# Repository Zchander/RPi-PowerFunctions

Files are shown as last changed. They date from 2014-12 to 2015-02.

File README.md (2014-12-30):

RPi-PowerFunctions
==================

A project to send commands over IR to a LEGO PowerFunctions receiver using an Raspberry Pi, I2C and an ATtiny2313

The Eagle project files have been added (including the PCB designs), as are the XMLRPC server files.

I'll try to update/create READMEs for the sub folders in the near future. Unfortunately my documenting skills are a bit 'subzero'

For this project I would like to thank a few people, who I will list down here. Please note that the order is random!
- Jurriaan Pruis (https://github.com/jurriaan/) for his project which gave me the idea(s)
- Dick de Wit (www.dansendelichtjes.nl) who helped me refresh some of my electronics skills
- A few from www.avrfreaks.net, some I will mention explicit:
- - kk6gm for inspiring me to NOT use _delay_ms/_delay_us in my code, but to use interrupts
- - kartman for his tutorial on multitasking on the AVR environment
- - david.prentice for directing me into a bug I introduced myself during code cleanup
- - clawson for his inspiring and helpful comments overall

(If I forgot someone, please let me know so I can include you on the list)

Xander

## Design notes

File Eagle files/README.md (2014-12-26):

The Eagle file(s) are made with version 7.2.0 and only contain the schematics. The PCB designs still have to be made.

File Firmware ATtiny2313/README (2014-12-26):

This version of the firmware is for the test environment without any external clock source. if you want to use an external clock, change the appropriate fuse settings and the define in the source(s). (This should be easy to find)

Xander

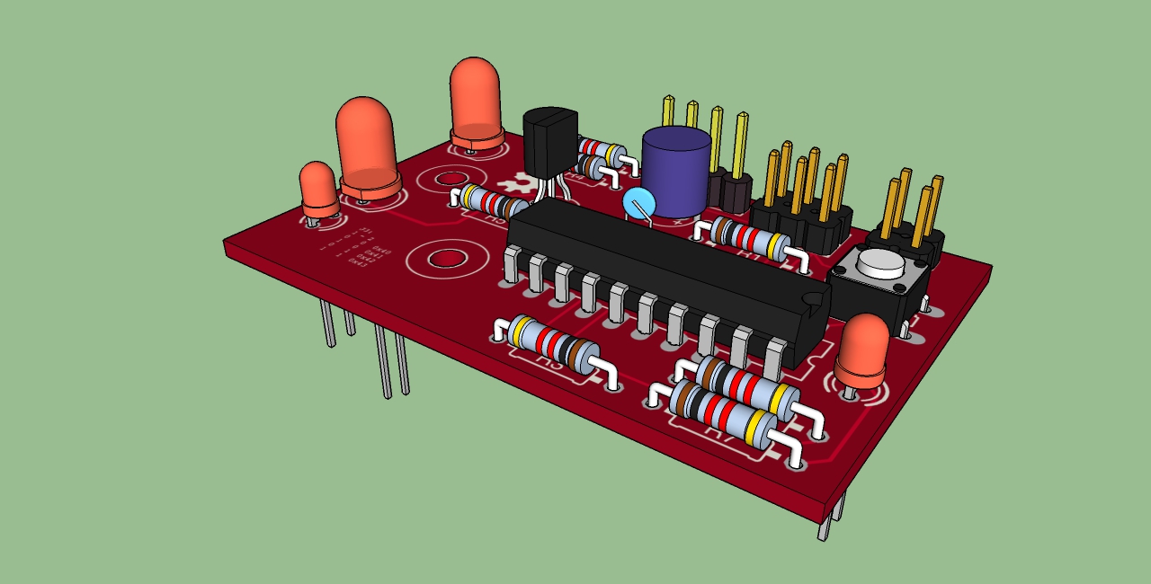
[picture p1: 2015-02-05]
Eagle files/RPi Lego PowerFunctions I2C/eagleUp/I2C Board Impression.jpg

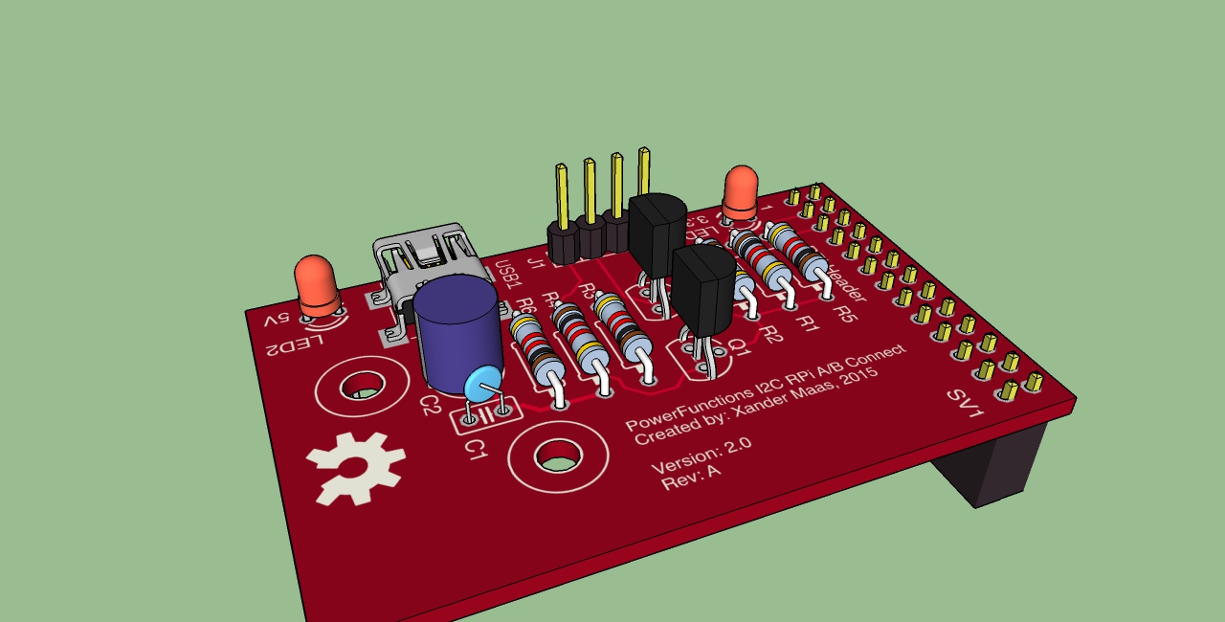
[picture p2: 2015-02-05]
Eagle files/RPi Lego PowerFunctions I2C/eagleUp/Impression I2C Connect Board.jpg

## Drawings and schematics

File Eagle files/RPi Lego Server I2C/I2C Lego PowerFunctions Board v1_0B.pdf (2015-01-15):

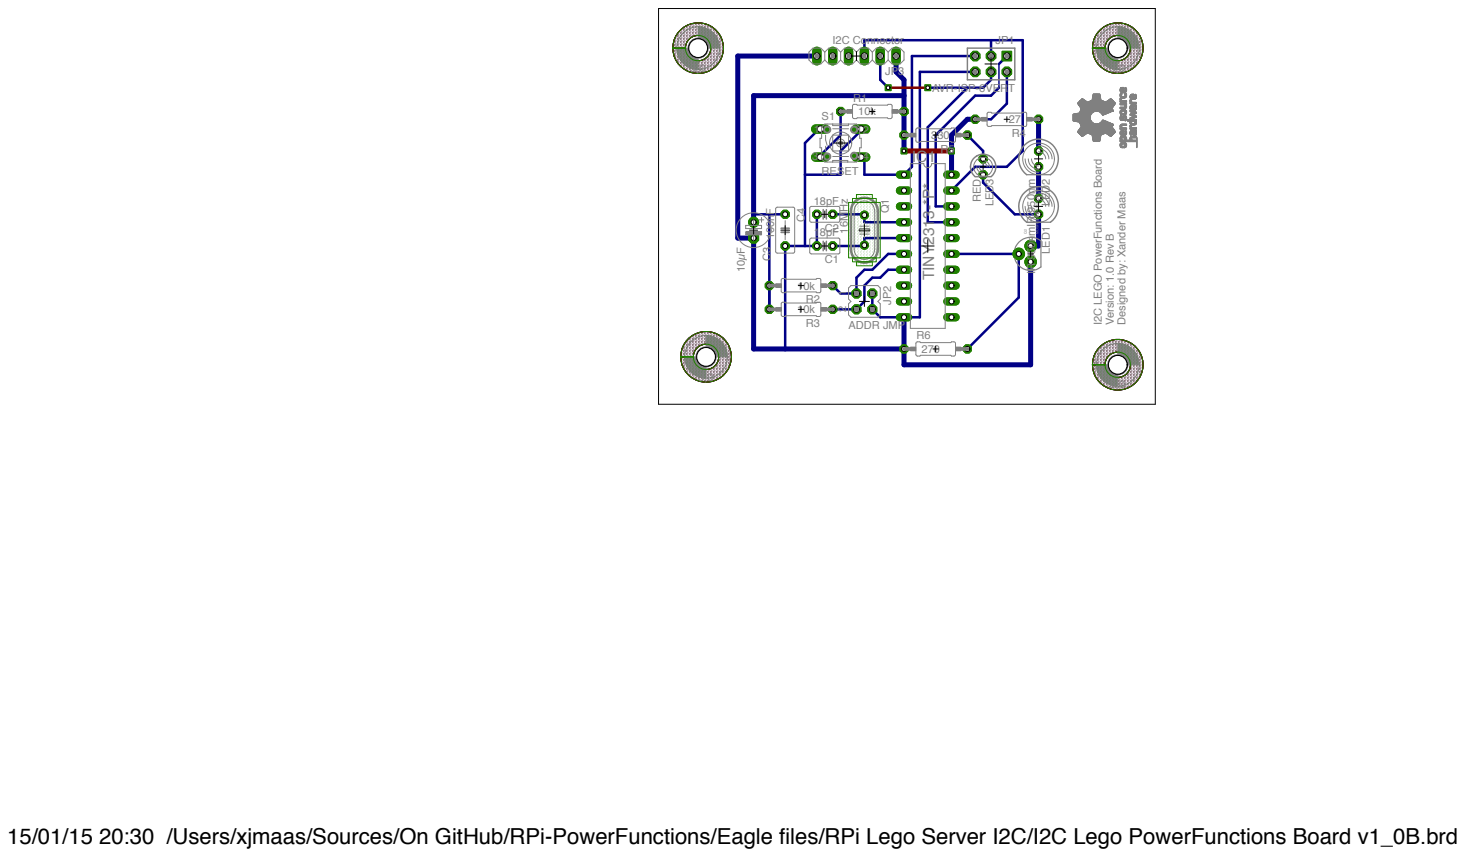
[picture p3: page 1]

15/01/15 20:30 /Users/xjmaas/Sources/On GitHub/RPi-PowerFunctions/Eagle files/RPi Lego Server I2C/I2C Lego PowerFunctions Board v1_0B.brd I2C LEGO PowerFunctions Board Version: 1.0 Rev B Designed by: Xander Maas

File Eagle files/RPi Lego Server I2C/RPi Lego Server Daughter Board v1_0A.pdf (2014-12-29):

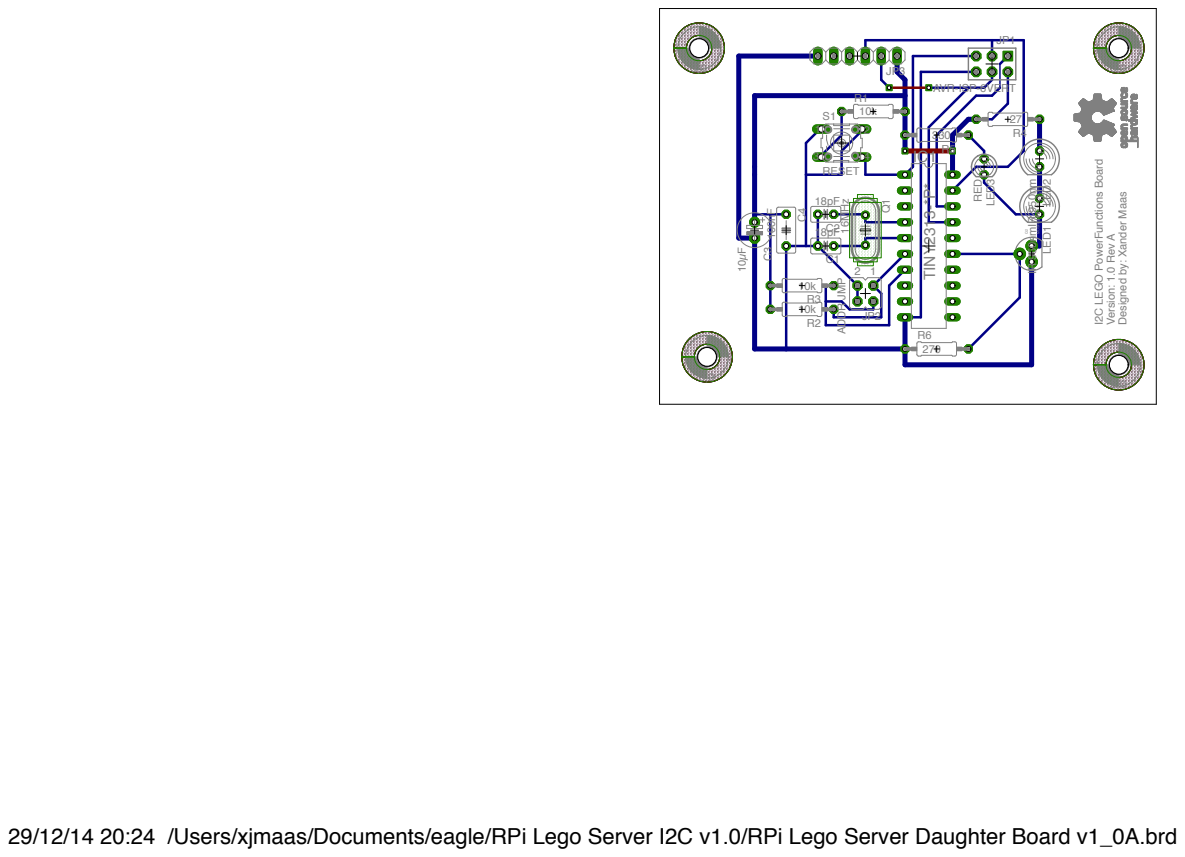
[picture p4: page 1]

29/12/14 20:24 /Users/xjmaas/Documents/eagle/RPi Lego Server I2C v1.0/RPi Lego Server Daughter Board v1_0A.brd I2C LEGO PowerFunctions Board Version: 1.0 Rev A Designed by: Xander Maas

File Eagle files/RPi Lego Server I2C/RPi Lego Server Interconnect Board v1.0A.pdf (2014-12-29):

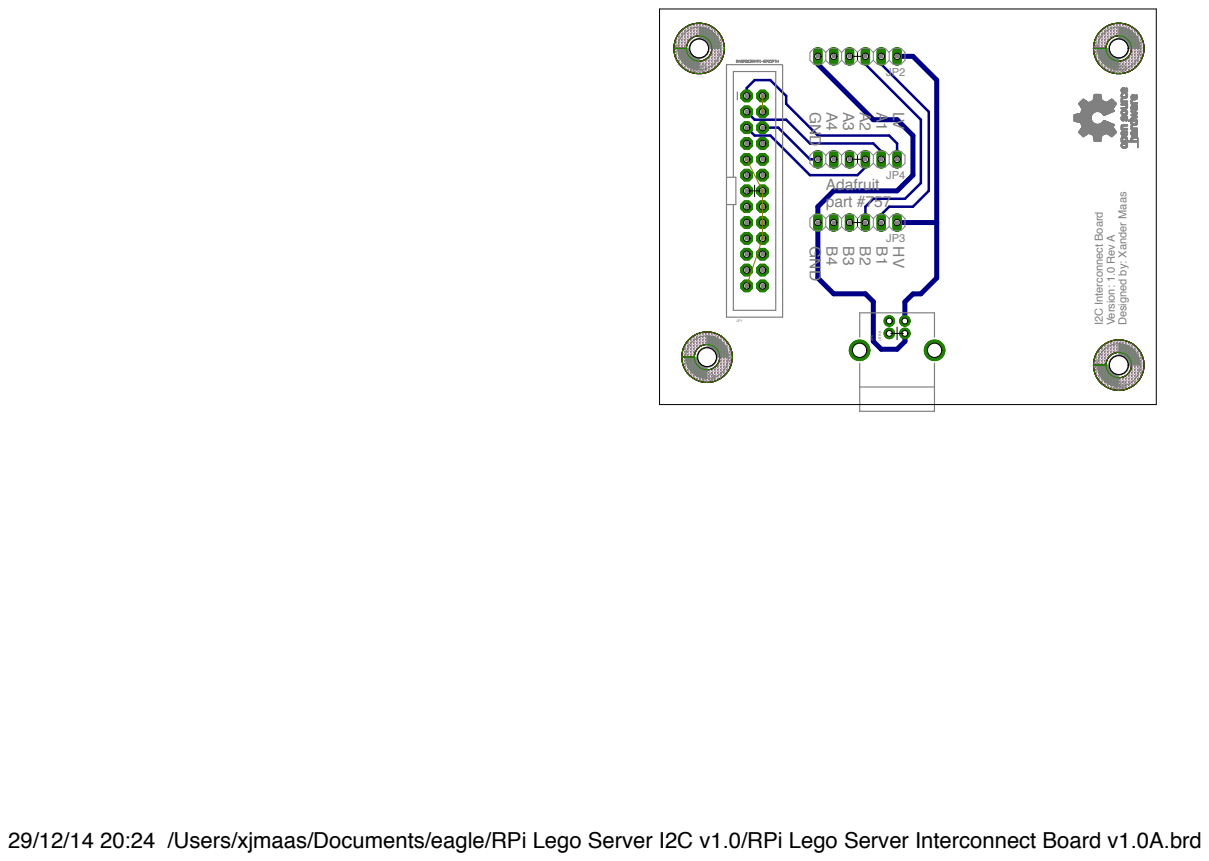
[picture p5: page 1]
Adafruit part #757; USB-B

29/12/14 20:24 /Users/xjmaas/Documents/eagle/RPi Lego Server I2C v1.0/RPi Lego Server Interconnect Board v1.0A.brd I2C Interconnect Board Version: 1.0 Rev A Designed by: Xander Maas GND B4B3B2B1HV GND A4A3A2A1LV

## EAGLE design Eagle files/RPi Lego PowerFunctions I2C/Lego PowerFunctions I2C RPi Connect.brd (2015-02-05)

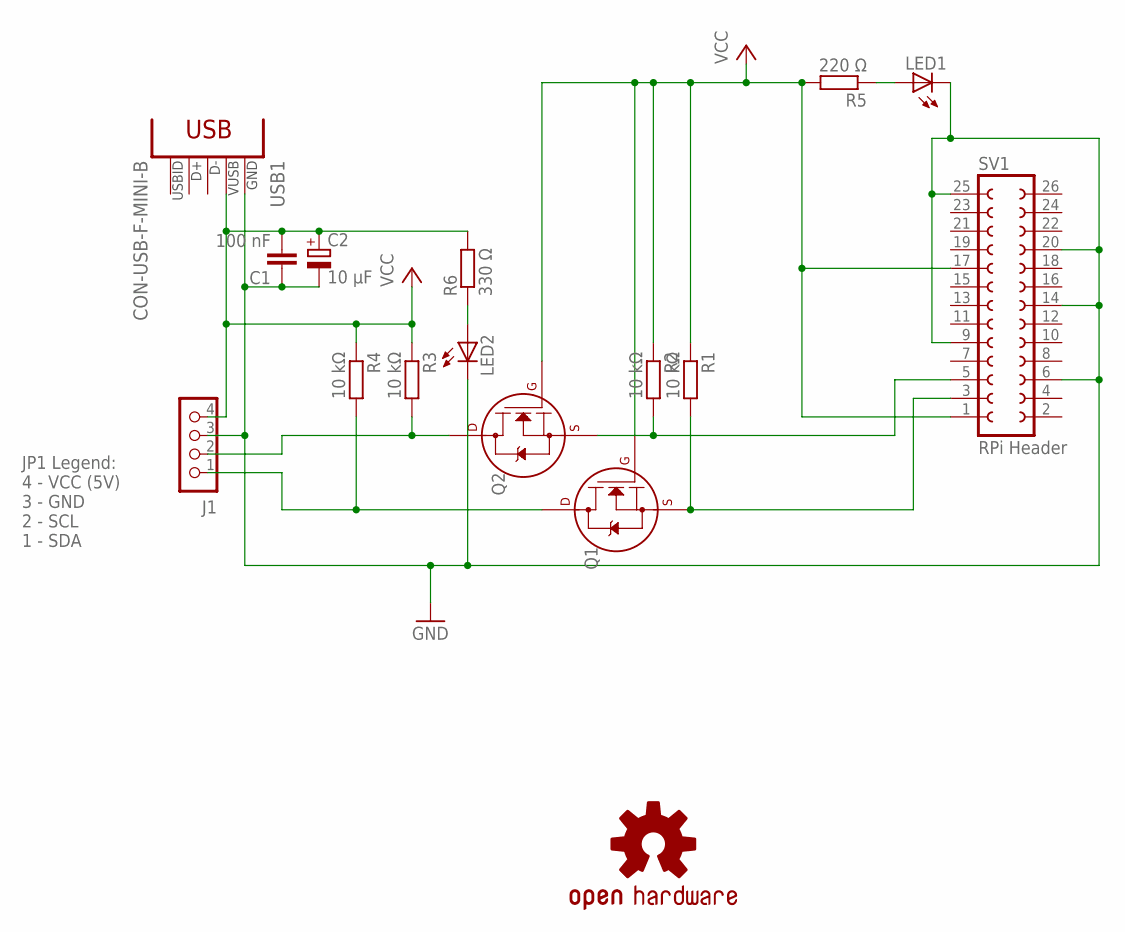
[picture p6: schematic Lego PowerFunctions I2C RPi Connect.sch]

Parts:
C1: 100 nF; C025-025X050
C2: 10 µF; E2,5-6
J1: CON_HEADER_1X04; M1X4
LED1, LED2: LED3MM
LOGO1: OSHW-LOGOL; OSHW-LOGO-L
Q1, Q2: 2N7000_TO92; TO-92
R1, R2, R3, R4: 10 kΩ; 0207/10
R5: 220 Ω; 0207/10
R6: 330 Ω; 0207/10
SV1: RPi Header; FE13-2
USB1: CON-USB-F-MINI-B; CONN_USB_MINI-B

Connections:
GND: C1.1, C2.-, J1.3, LED1.K (C), LED2.K (C), SV1.6, SV1.9, SV1.14, SV1.20, SV1.25, USB1.GND
unnamed: LED1.A, R5.1
unnamed: LED2.A, R6.1
unnamed: Q1.1 (S), R1.2, SV1.3
SCL_HV: J1.2, Q2.3 (D), R3.2
SCL_LV: Q2.1 (S), R2.2, SV1.5
SDA_HV: J1.1, Q1.3 (D), R4.2
VCC_HV: C1.2, C2.+, J1.4, R3.1, R4.1, R6.2, USB1.VUSB
VCC_LV: Q1.2 (G), Q2.2 (G), R1.1, R2.1, R5.2, SV1.1, SV1.17

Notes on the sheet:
JP1 Legend: 4 - VCC (5V) 3 - GND 2 - SCL 1 - SDA

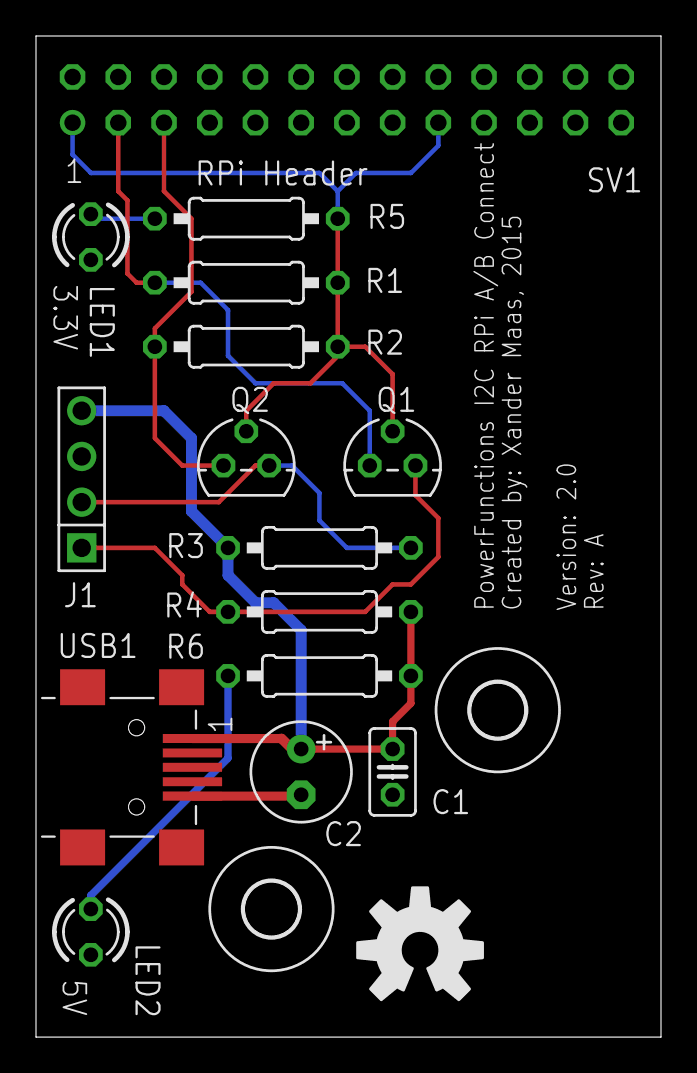
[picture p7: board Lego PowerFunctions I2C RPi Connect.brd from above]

Board: 2 copper layers, 34.7 x 55.6 mm, 18 parts (1 on the bottom side), 9 nets.

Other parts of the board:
U$1, U$3: 3,0

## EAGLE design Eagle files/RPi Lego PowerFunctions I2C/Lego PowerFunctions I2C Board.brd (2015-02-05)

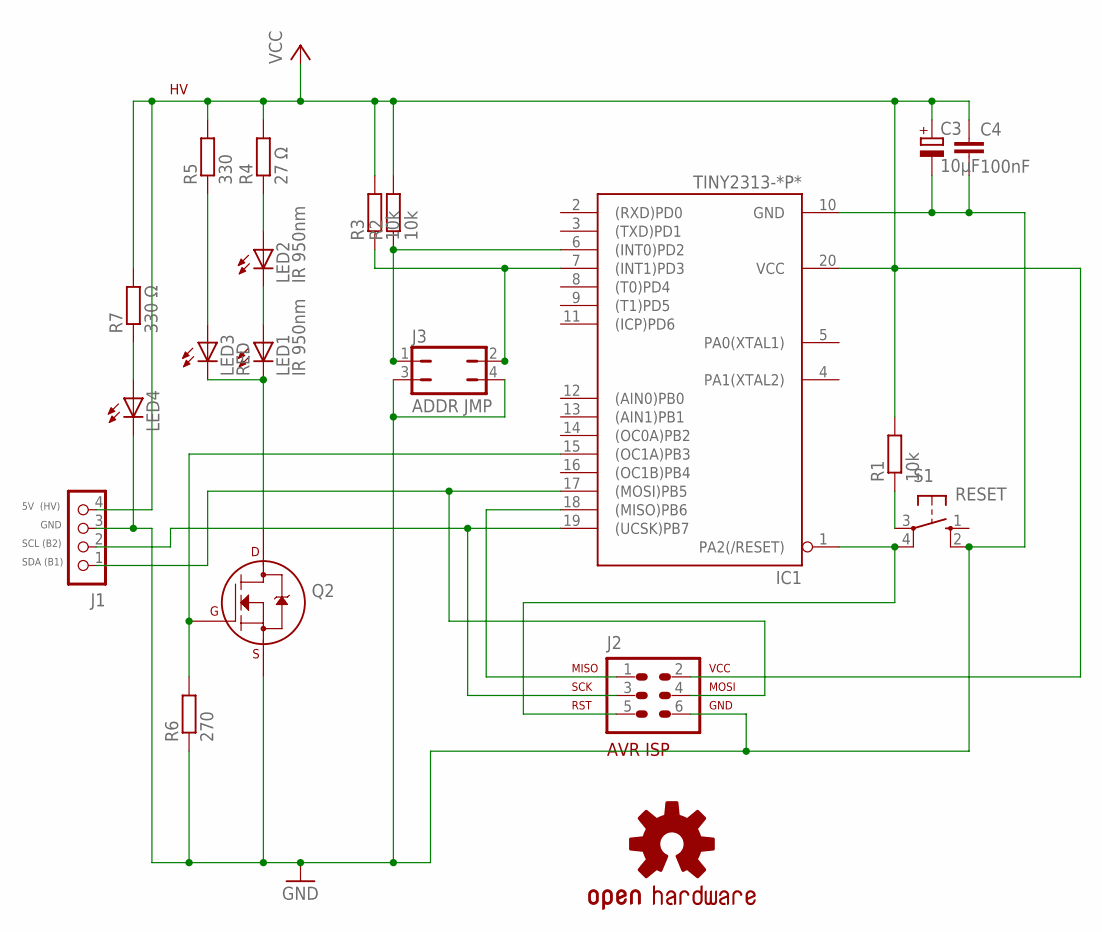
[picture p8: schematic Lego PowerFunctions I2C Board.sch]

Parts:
C3: 10µF; E2,5-6
C4: 100nF; C025-025X050
IC1: TINY2313-*P*; DIL20
J1: CON_HEADER_1X04; M1X4
J2: AVR-ISP-6VERT; AVR-ISP-6
J3: ADDR JMP; JP2Q
LED1, LED2: IR 950nm; LED5MM
LED3: RED; LED3MM
LED4: LED3MM
LOGO1: OSHW-LOGOM; OSHW-LOGO-M
Q2: 2N7000_TO92; TO-92
R1, R2, R3: 10k; 0207/10
R4: 27 Ω; 0207/10
R5: 330; 0207/10
R6: 270; 0207/10
R7: 330 Ω; 0207/10
S1: RESET; B3F-10XX

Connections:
GND: C3.-, C4.2, IC1.10 (GND), J1.3, J2.6, J3.3, J3.4, LED4.K (C), Q2.1 (S), R6.1, S1.2 (S1)
I2CADDRH: IC1.7 ((INT1)PD3), J3.2, R3.1
I2CADDRL: IC1.6 ((INT0)PD2), J3.1, R2.1
MISO: IC1.18 ((MISO)PB6), J2.1
MOSI: IC1.17 ((MOSI)PB5), J1.1, J2.4
unnamed: LED4.A, R7.1
unnamed: R1.1, S1.3
unnamed: LED2.A, R4.1
unnamed: LED3.A, R5.1
unnamed: LED1.A, LED2.K (C)
unnamed: LED1.K (C), LED3.K (C), Q2.3 (D)
unnamed: IC1.15 ((OC1A)PB3), Q2.2 (G), R6.2
RST: IC1.1 (PA2(/RESET)), J2.5, S1.4 (P1)
SCL: IC1.19 ((UCSK)PB7), J1.2, J2.3
VCC: C3.+, C4.1, IC1.20 (VCC), J1.4, J2.2, R1.2, R2.2, R3.2, R4.2, R5.2, R7.2

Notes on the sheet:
5V (HV)
SDA (B1)
SCL (B2)
GND

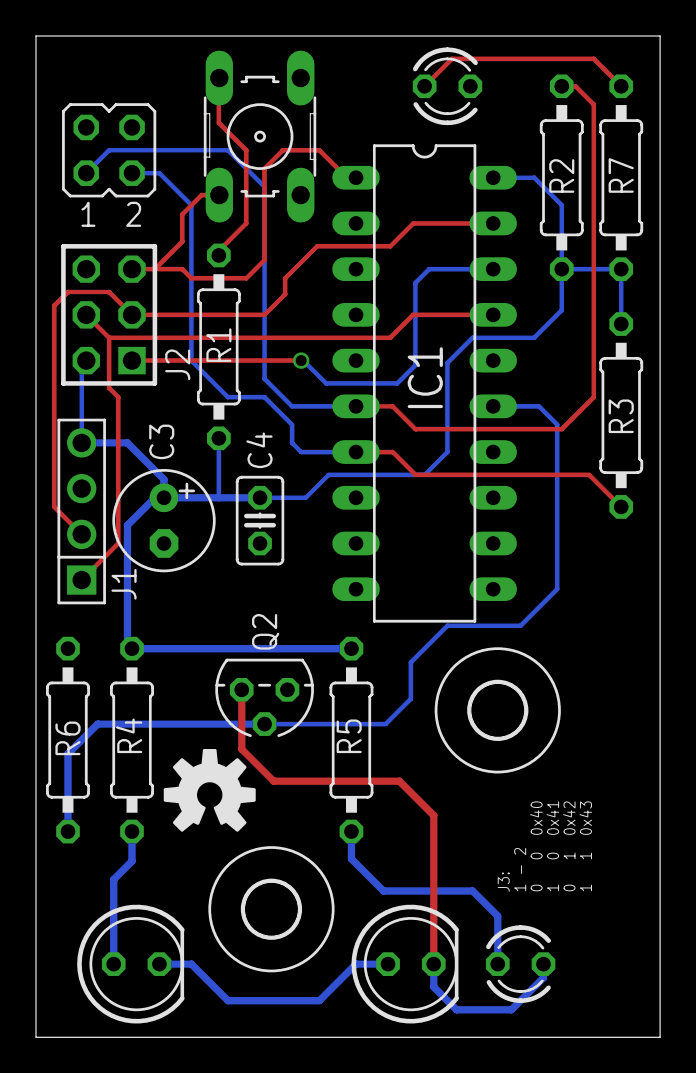
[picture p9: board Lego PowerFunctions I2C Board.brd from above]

Board: 2 copper layers, 34.7 x 55.6 mm, 22 parts (0 on the bottom side), 15 nets.

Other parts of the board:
U$1, U$2: 3,0

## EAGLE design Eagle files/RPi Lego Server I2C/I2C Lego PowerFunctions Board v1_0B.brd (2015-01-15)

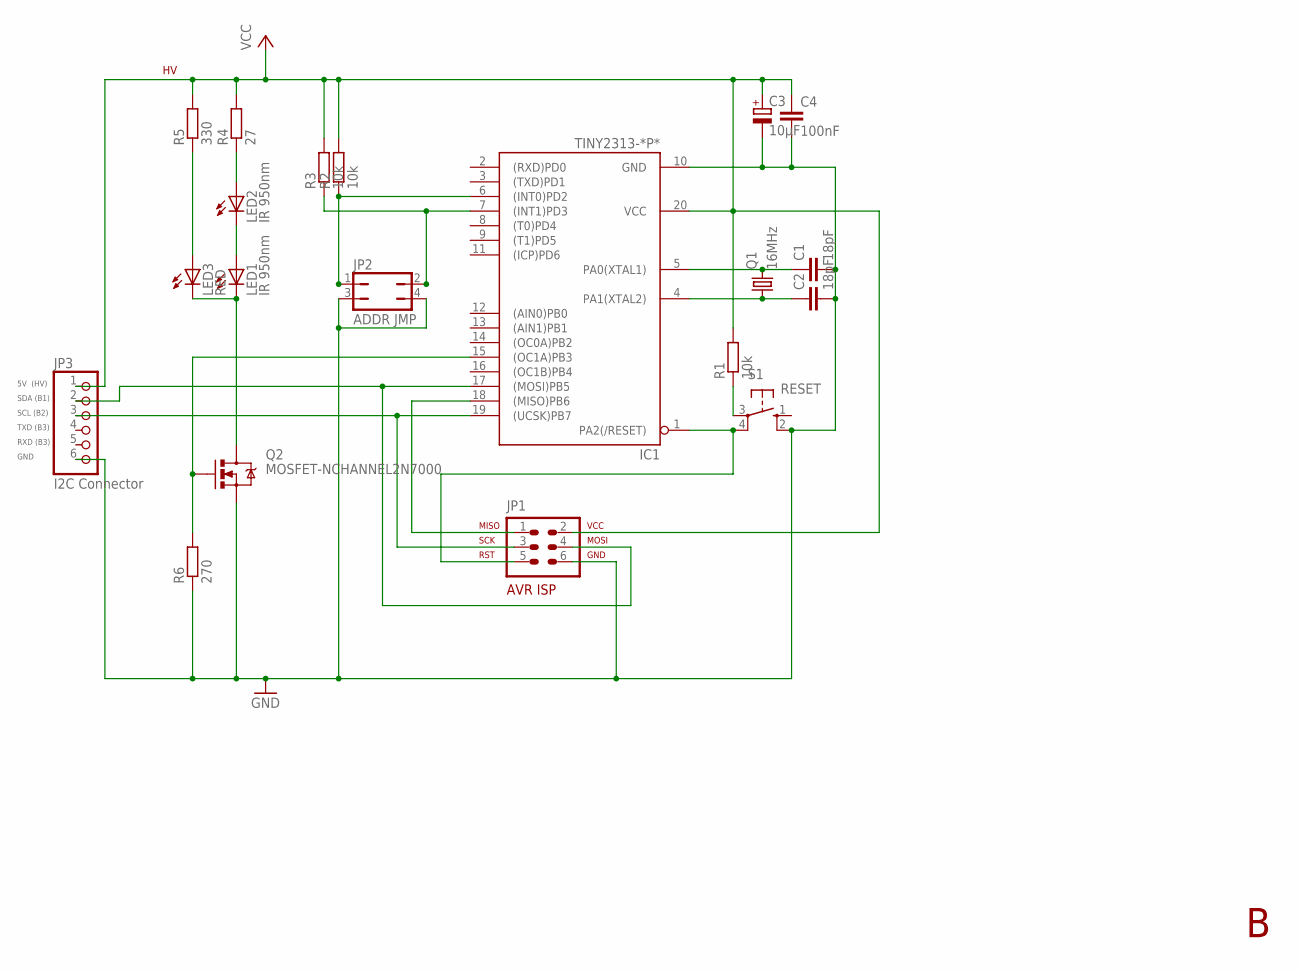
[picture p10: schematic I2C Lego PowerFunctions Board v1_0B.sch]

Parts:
C1, C2: 18pF; C025-025X050
C3: 10µF; E2,5-6
C4: 100nF; C050-030X075
IC1: TINY2313-*P*; DIL20
JP1: AVR-ISP-6VERT; AVR-ISP-6
JP2: ADDR JMP; JP2Q
JP3: I2C Connector; 1X06
LED1, LED2: IR 950nm; LED5MM
LED3: RED; LED3MM
Q1: 16MHz; HC49/S
Q2: MOSFET-NCHANNEL2N7000; TO-92
R1, R2, R3: 10k; 0207/10
R4: 27; 0207/10
R5: 330; 0207/10
R6: 270; 0207/10
S1: RESET; B3F-10XX

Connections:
GND: C1.2, C2.2, C3.-, C4.2, IC1.10 (GND), JP1.6, JP2.3, JP2.4, JP3.6, Q2.1 (S), R6.1, S1.2 (S1)
I2CADDRH: IC1.7 ((INT1)PD3), JP2.2, R3.1
I2CADDRL: IC1.6 ((INT0)PD2), JP2.1, R2.1
MISO: IC1.18 ((MISO)PB6), JP1.1
MOSI: IC1.17 ((MOSI)PB5), JP1.4, JP3.2
unnamed: R1.1, S1.3
unnamed: LED2.A, R4.1
unnamed: LED3.A, R5.1
unnamed: LED1.A, LED2.K (C)
unnamed: LED1.K (C), LED3.K (C), Q2.3 (D)
unnamed: IC1.15 ((OC1A)PB3), Q2.2 (G), R6.2
RST: IC1.1 (PA2(/RESET)), JP1.5, S1.4 (P1)
SCL: IC1.19 ((UCSK)PB7), JP1.3, JP3.3
VCC: C3.+, C4.1, IC1.20 (VCC), JP1.2, JP3.1, R1.2, R2.2, R3.2, R4.2, R5.2
XTAL1: C2.1, IC1.4 (PA1(XTAL2)), Q1.1
XTAL2: C1.1, IC1.5 (PA0(XTAL1)), Q1.2

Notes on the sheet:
5V (HV)
SDA (B1)
SCL (B2)
GND
TXD (B3)
RXD (B3)

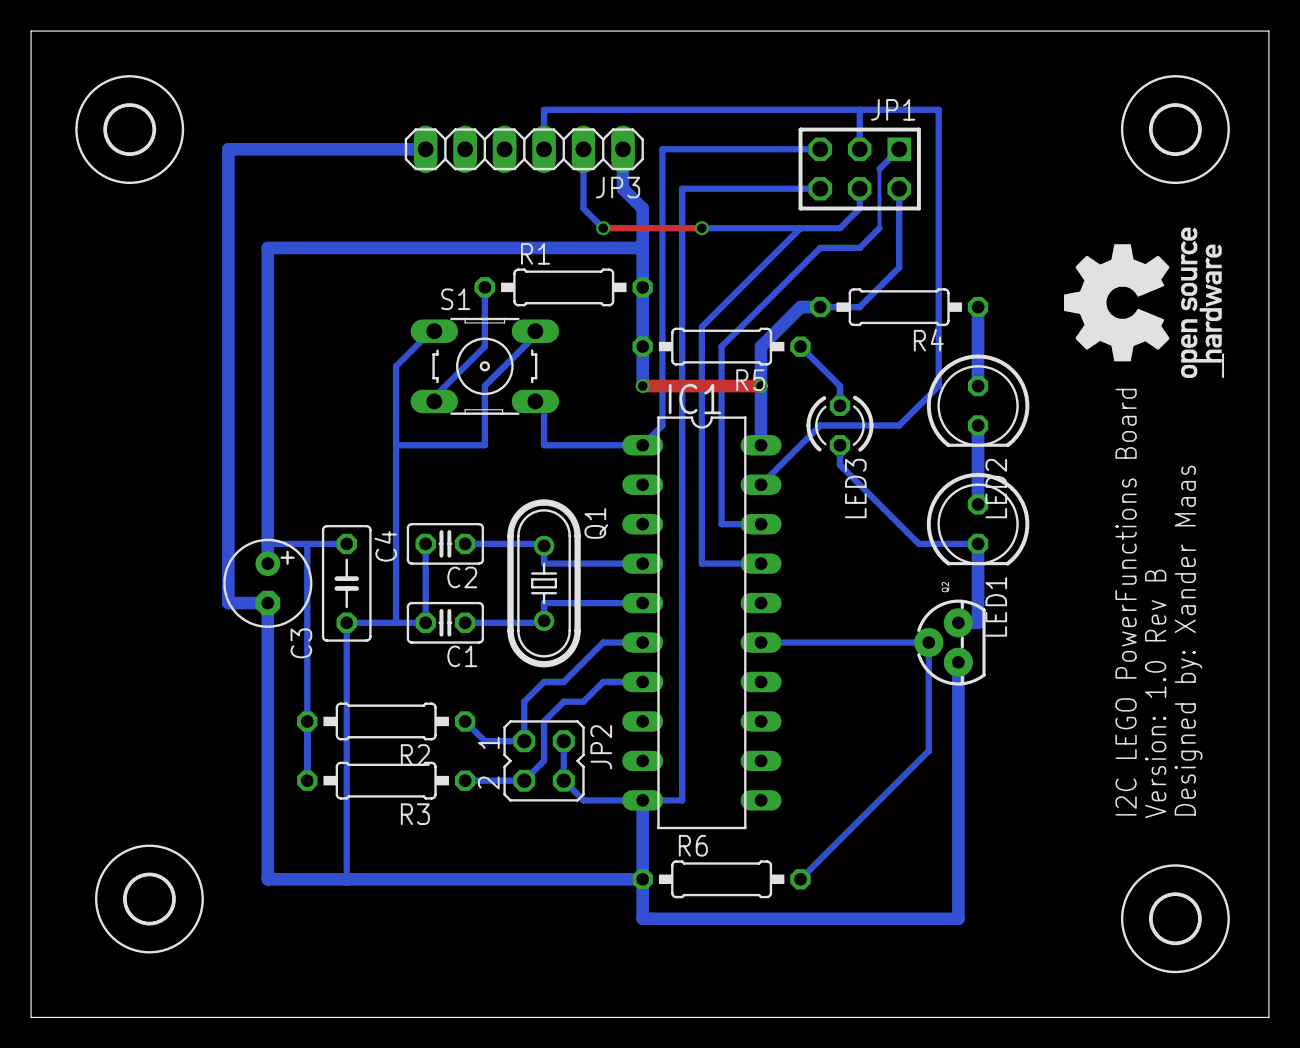
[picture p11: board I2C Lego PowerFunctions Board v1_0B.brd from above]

Board: 2 copper layers, 79.7 x 63.5 mm, 24 parts (0 on the bottom side), 16 nets.

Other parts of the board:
U$2, U$3, U$4, U$5: 3,0

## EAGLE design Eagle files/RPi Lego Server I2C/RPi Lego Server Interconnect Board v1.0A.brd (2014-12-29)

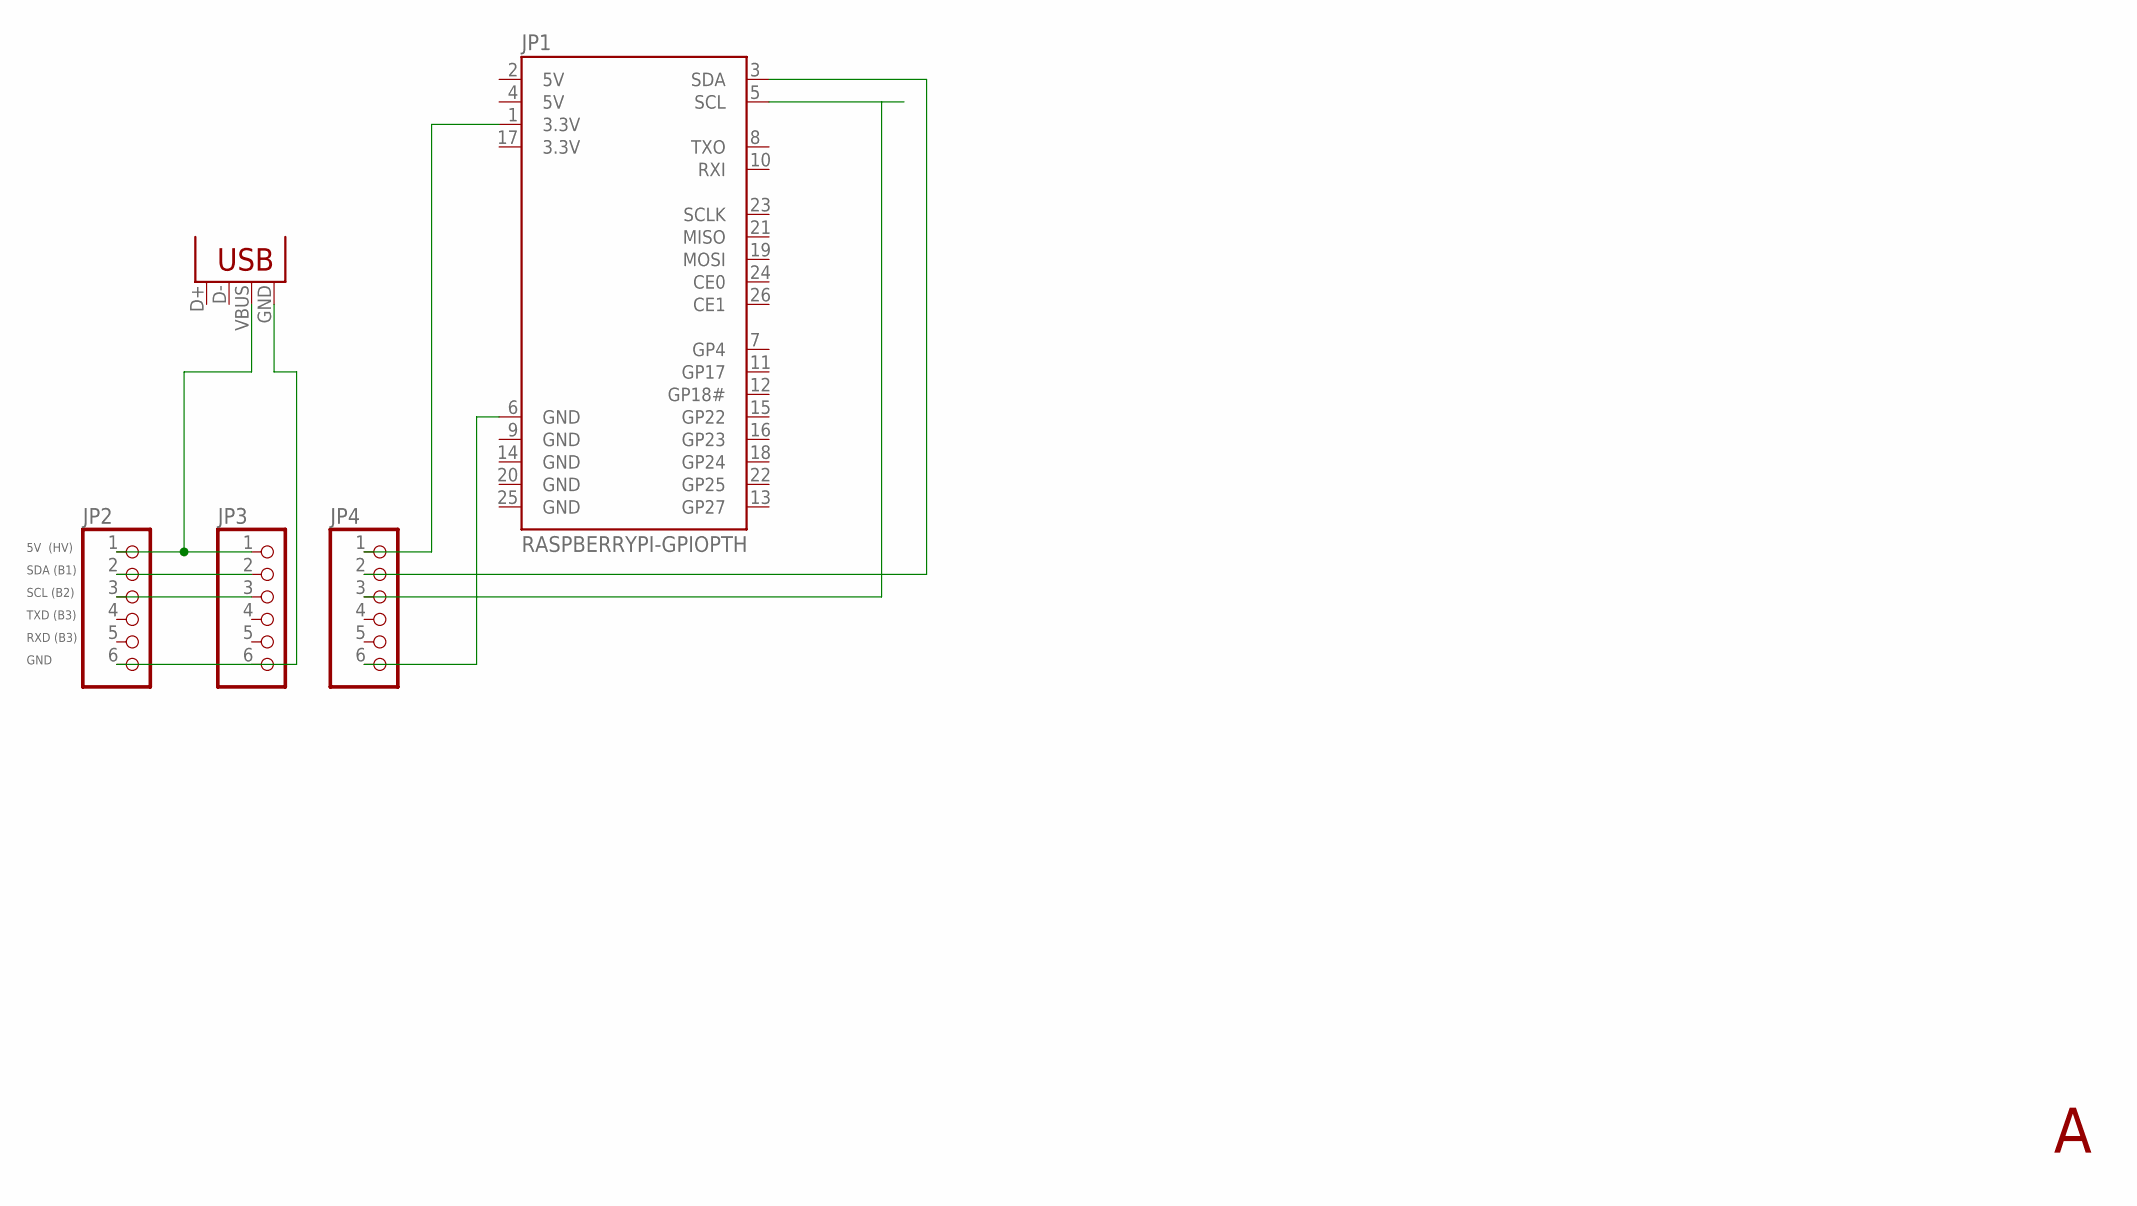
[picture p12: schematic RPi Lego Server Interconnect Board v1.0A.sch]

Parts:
JP1: RASPBERRYPI-GPIOPTH; 2X13-SHROUDED
JP2, JP3, JP4: PINHD-1X6; 1X06
JP5: USB-B; USB-B-PTH

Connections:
3.3V: JP1.17 (3.3V)
5V: JP1.2 (5V), JP1.4 (5V)
GND: JP1.9 (GND), JP1.14 (GND), JP1.20 (GND), JP1.25 (GND)
unnamed: JP1.3 (SDA), JP4.2
unnamed: JP1.5 (SCL), JP4.3
unnamed: JP1.6 (GND), JP4.6
unnamed: JP2.6, JP3.6, JP5.GND
unnamed: JP2.1, JP3.1, JP5.VBUS
unnamed: JP2.2, JP3.2
unnamed: JP2.3, JP3.3
unnamed: JP1.1 (3.3V), JP4.1

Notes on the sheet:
5V (HV)
SDA (B1)
SCL (B2)
GND
TXD (B3)
RXD (B3)

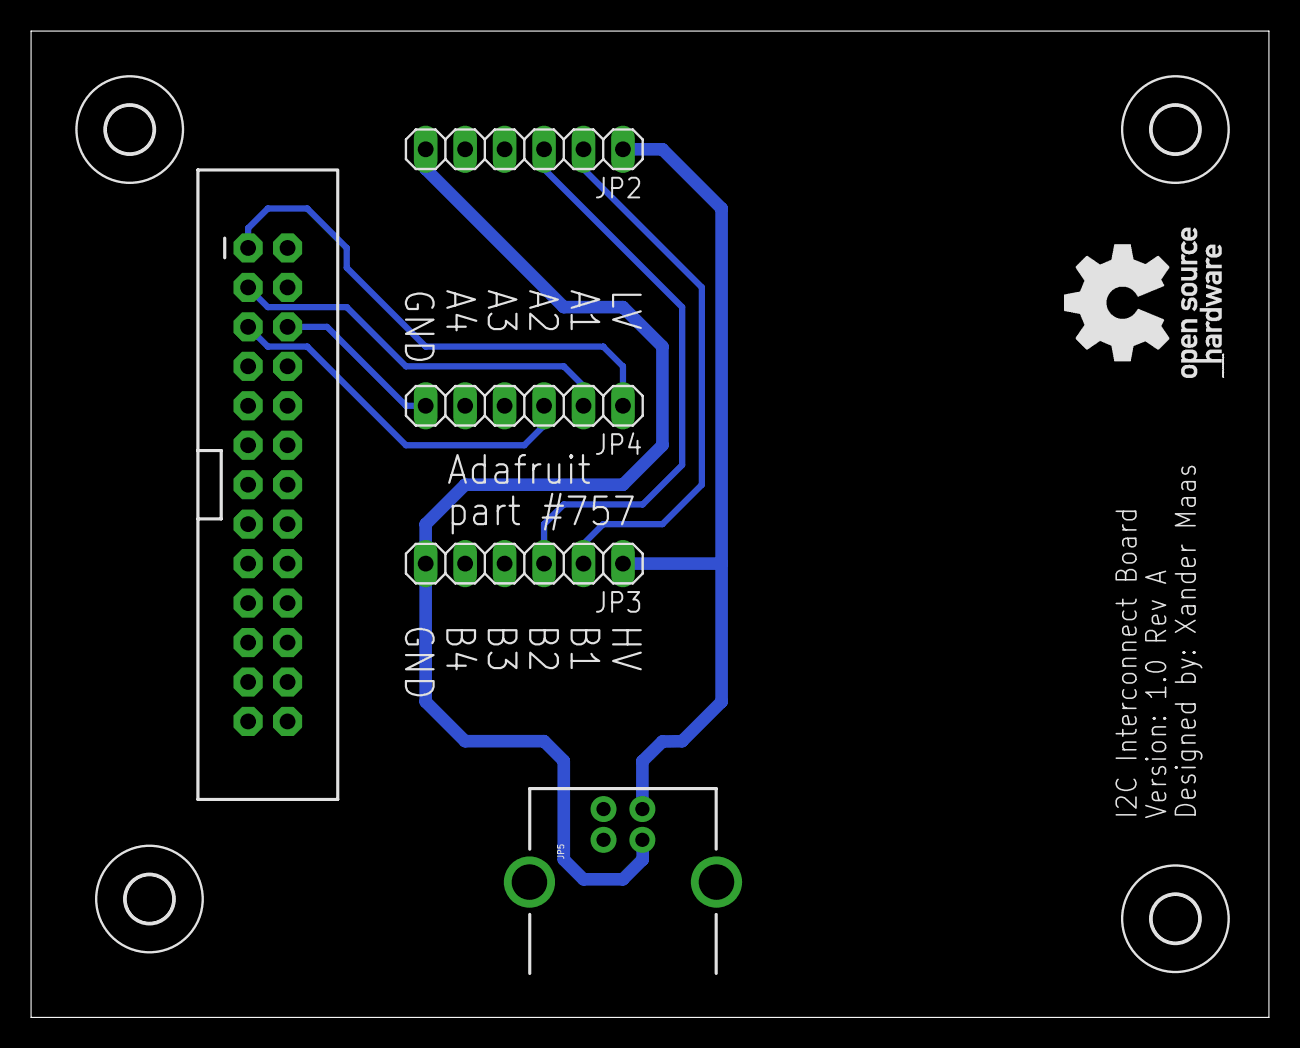
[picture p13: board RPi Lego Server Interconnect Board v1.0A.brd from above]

Board: 2 copper layers, 79.7 x 63.5 mm, 9 parts (0 on the bottom side), 10 nets.

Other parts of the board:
U$2, U$3, U$4, U$5: 3,0

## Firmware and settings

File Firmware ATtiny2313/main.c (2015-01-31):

/*
 * Lego PowerFunctions I2C Slave
 *
 * main.c
 *
 * Author:	Xander Maas, <xander@xjmaas.nl>
 * Created:	17 oct 2014
 *
 * Copyright (c) 2014, Xander Maas
 * Copyright (c) 2010, Russel Bull (Multi-tasking code)
 *
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
 * Warranties:
 *      NONE, USE AT OWN RISK
 * 
 * Note(s):
 *      This file is based on code from avrfreaks.net
 *      Thread => [TUT][C]Multi-tasking tutorial part 1
 *      (http://www.avrfreaks.net/forum/tutc-multi-tasking-tutorial-part-1)
 *      The code on which the multi-tasking os based is copyrighted, but free
 *      for any use.
 *
 * Change history:
 *      date        Description
 *      26 Dec 2014 First public release.
 *      30 Jan 2015	Added a checksum recalculation to task1() as we also have
 *      			to toggle a bit in nibble1 of the pfCommand
 *      31 Jan 2015	Found aout that Combo PWM uses the Escape bit and moves the
 *      			address bit to bit 0 of nibble 1. We don't want to toggle
 *      			this bit when using Combo PWM
 */

#include <avr/io.h>
#include <avr/interrupt.h>
#include <avr/pgmspace.h>
#include "usiTwiSlave.h"
#include "main.h"
#include "powerfunctions.h"

/*
 * A task gets dispatched every tick_flag tick
 */
void task_dispatch(void) {
	// Scan the task bits for an active task and execute it
	unsigned char task;

	// Take care of the task timers. If the value == 0, skip it
	// else decrement it. If it decrements to zero (0), activate the task
	// associated with it
	task = 0 ;
	while ( task < NUM_TASKS ) {
		if ( task_timers[task] ) {
			// Decrement the timer
			task_timers[task]--;
			if ( task_timers[task] == 0 ) {
				// If == 0, activate the task bit
				task_set(task);
			}
		}
		task++;
	}

	// Start with the most significant task
	task = 0;

	while ( task < NUM_TASKS ) {
		if ( (task_bits & pgm_read_byte(&bit_mask[task])) ) {
			// If active task has been found ...
			break;
		}
		// Otherwise try the next task
		task++;
	}
	switch ( task ) {
         case 0:
			task0();
			break;
		case 1:
			task1();
			break;
        // No tasks were active!!
		default:
			break;
	}
}

/*
 * Enable a task for execution
 */
void task_set(unsigned char task) {
	// Sets a task bit
	task_bits |= pgm_read_byte(&bit_mask[task]);
}

/*
 * Disables a task
 */
void task_reset(unsigned char task) {
	// Resets a task bit
	task_bits &= (~pgm_read_byte(&bit_mask[task]));
}

/*
 * The tasks
 */
// This task will test the PFREG0 register and act accordingly if both values
// have been received (both bits PFLB and PFHB are set)
void task0(void) {
	// We want to run this task every 100ms (== 10Hz)
	task_timers[0] = 10;
    
	// Check if th PFWORD flasg is set (both bytes have been received)
	if ( (PFREG0 & ((1 << PFLB) | (1 << PFHB))) ) {
        pfCommand = ((uint16_t)highByte << 8) | lowByte;
        
		// Make sure the PFREG0 register is updated, so we know a new
		// command has been received
		PFREG0 |= (1 << PFCMD0);

		// Before we return, reset the PFREG0 bits and the I2C registers
		PFREG0 &= ~(1 << PFLB);
		PFREG0 &= ~(1 << PFHB);
        highByte = 0x00;
        lowByte = 0x00;
	}
	// When the task has finished, reset the task
	task_reset(0);
}

// This task will be used to process the received command
// It will run every 100mSec
void task1(void) {
    task_timers[1] = 10;
    
#ifdef DEBUG
    PORTD |= (1 << PD6);
#endif
    
    if ( (PFREG0 & (1 << PFCMD0)) ) {
        converted_byte(highByte, lowByte);
        // if a (complete) PF command has been received (2 bytes)
        // process it
        for ( uint8_t i = 0; i < 6; i++ ) {
			// We have to toggle the Toggle bit, but this also implies a
			// recalculation of nibble 4 (checksum)
			uint8_t nib1 = pfCommand >> 12 & 0xf;
			uint8_t nib2 = pfCommand >> 8 & 0xf;
			uint8_t nib3 = pfCommand >> 4 & 0xf;
			
			// We only want to toggle this bit when bit 3 is NOT set
			// Which means, we are using PWM Combo mode
			if ((nib1 & ~(1 << 2))) {
				// Toggle the bit (MSB in nibble)
				nib1 = nib1 ^ 8;
			}
			uint8_t nib4 = 0xf ^ nib1 ^ nib2 ^ nib3;
			// Constuct our new command
			pfCommand = nib1 << 12 | nib2 << 8 | nib3 << 4 | nib4;
            // Send the command 6 times!
            pause(i);

            process_command(pfCommand);
        }
    }

#ifdef DEBUG
    PORTD &= ~(1 << PD6);
#endif
    
    // Reset the bits in the PFREG0 register
    PFREG0 &= ~(1 << PFCMD0);
    PFREG0 &= ~(1 << PFHB);
    PFREG0 &= ~(1 << PFLB);
    /*
#ifdef DEBUG
    // Clear the two test LEDS
    PORTD &= ~(1 << I2C_RCVD_LOW);
    PORTD &= ~(1 << I2C_RCVD_HGH);
#endif
     */
    
	// When the task has finished, reset the task
	task_reset(1);
}

/*
 * Call this routine to initialize all peripherals
 */
void init_devices(void) {
	// Stop all errant interrupts until we have setup the MCU
	cli();

#ifdef DEBUG
    /*
	DDRD |= (1 << I2C_RCVD_LOW);
	PORTD &= ~(1 << I2C_RCVD_LOW);
	DDRD |= (1 <<  I2C_RCVD_HGH);
	PORTD &= ~(1 << I2C_RCVD_HGH);
    */
    
    // Also for debug purposes
    DDRB |= (1 << PB0) | (1 << PB1);
    DDRD |= (1 << PD4) | (1 << PD6);
    
    // Turn them off initially
    PORTB &= ~(1 << PB0);
    PORTB &= ~(1 << PB1);
    PORTD &= ~(1 << PD4);
    PORTD &= ~(1 << PD6);
#endif

	// Initialize TIMER0
	timer0_init();
    
    // Initialize TIMER1
    timer1_init();
    
    // Re-enable all interrupts
	sei();

    init_serial();
    
	// Set up our I2C interface/bus
	setupI2C();
}

/* 
 * Initialize our serial port
 */
void init_serial(void) {
    UBRRL = 25;             /* 19200 baud */
    
    UCSRB = (1 << RXEN) | (1 << TXEN);
    UCSRC = (1 << UCSZ1) | (1 << UCSZ0);
}

void converted_byte(char byte1, char byte2) {
    
    unsigned char buf[] = { byte1, byte2};
    
    char str[20];
    
    unsigned char *pin = buf;
    const char *hex = "0123456789ABCDEF";
    char *pout = str;
    int i = 0;
    for ( i = 0; i < sizeof(buf)-1; i++) {
        *pout++ = hex[(*pin>>4)&0xf];
        *pout++ = hex[(*pin++)&0xf];
    }
    *pout++ = hex[(*pin>>4)&0xf];
    *pout++ = hex[(*pin++)&0xf];
    //    *pout = 0x00; // Null-terminator
    
    converted =  str;
}


void usart_putchar(char data) {
    // Wait for empty transmit buffer
    while ( !(UCSRA & (_BV(UDRE))) );
    // Start transmission
    UDR = data;
}

/*
 * Send string over serial
 */
void send_string(char *msg) {
    while ( *msg ) {
        usart_putchar( *msg);
        msg++;
    }
}

/* 
 * Initialize TIMER0 - The timer we use for the tasks
 * WGM:				CTC
 * Pre-Scale:		1024
 * Desired value:	10 mSec
 * Actual value:	9.8 mSec
 */
void timer0_init(void) {
	// Stop
	TCCR0B = 0x00;

	// Set the count
	TCNT0 = 0x00;

	// Set CTC Mode
	TCCR0A |= (1 << WGM01);

    // Use Compare Interrupt Register A for TIMER0
    TIMSK |= (1 << OCIE0A);
    
	// Set the count value
    OCR0A = OCR0A_VALUE;

	// Start TIMER0 by setting the pre-scale
	TCCR0B |= (1 << CS00);
	TCCR0B |= (1 << CS02);
}

/* Initialize TIMER1 - The timer we want to use to create the 76kHz
 * carrier later on. First we want to test it with 2 Hz carrier.
 * The actual blink rate will be half... 1 cycle will be used to 
 * turn the LED on, the other will be used to turn the LED off
 *
 * 1Hz blink, 2Hz carrier
 * WGM:             CTC
 * Pre-Scale:       64
 * Desired value:   500 mSec
 * Actual value:    499.992 mSec (rounding issue?)
 * Desired counter: 62499
 * actual counter:  62499 == 0xf423
 *
 * 38kHz blink, 76kHz carrier
 * WGM:             CTC
 * Pre-Scale:       1
 * Desired value:   13.157 uSec
 * Actual value:    13.000 uSec
 * Desired counter: 104.3
 * Actual counter:  104 == 0x68
 */
void timer1_init(void) {
    // Mode:            CTC     WGM[13:10]  = 0100
    // Prescale:        1       CS[12:10]   = 001
    // Compare Match:   toggle  COM1A[1:0]  = 01

    // First stop the timer
    TCCR1B = 0x00;
    
    // Use Compare Interrupt Register A from TIMER1
    TIMSK |= (1 << OCIE1A);
    
    // Set OCR1A to our calculated value
    OCR1A = (uint16_t) OCR1A_VALUE;
    
    // Set the mode
    TCCR1B |= (1 << WGM12);
    
    // Set the compare match toggle on OC1A
    TCCR1A |= (1 << COM1A0);
    
    // Start the timer by setting the prescale value
    TCCR1B |= (1 << CS10);
}

/*
 * The interrupt handler(s)
 */
ISR (TIMER0_COMPA_vect) {
	// TIMER0 has overflowed
	tick_flag = 1;
}

ISR (TIMER1_COMPA_vect) {
    // empty by design
#ifdef DEBUG
    PORTD ^= (1 << PD4);
#endif
    cycles_count++;
}

/*
 * This sets up the I2C bus
 */
void setupI2C(void) {
	usiTwiSlaveInit(i2cAddress(),
			i2cReadFromRegister,
			i2cWriteToRegister);
}

/*
 * Determine the slave address we are listening on
 */
uint8_t i2cAddress(void) {
	// We use two pins to 'create' the address we are listening on
	// Set the two address pins as inputs
	DDRD &= ~(1 << ADDR_PIN0);
	DDRD &= ~(1 << ADDR_PIN1);

	// Disable the internal Pull-Up resistors
	PORTD &= ~(1 << ADDR_PIN0);
	PORTD &= ~(1 << ADDR_PIN1);

	// The base address is 0x40
	uint8_t address = 0x40;

	// The bit mask is 00001100b == 12 == 0x0c
	uint8_t subAddress = ~PIND & 0x0c;

	// Right shift the subAddress 2 bits
	subAddress = (subAddress >> 2);

	// Store our channel (which is the subAddress + 1)
	channel = subAddress + 1;

	// Store our address
	address = address + subAddress;

	return address;
}

uint8_t i2cReadFromRegister(uint8_t reg) {
	switch (reg) {
		case 0:
			//Return the major version number
			return MAJOR_VERSION;
			break;
		case 1:
			// Return minor version number
			return MINOR_VERSION;
			break;
		case 2:
			// Return revision number
			return REVISION;
			break;
		case 3:
			// Return release
			return RELEASE;
			break;
		case 10:
			// Return byte #1 of the board identification
			return 'P';
			break;
		case 11:
			// Return byte #2 of the board identification
			return 'F';
			break;
		case 12:
			// Return byte #3 of the board identification
			return 'X';
			break;
		case 13:
			// Return byte #4 of the board identification
			return 'M';
			break;
		default:
			// Seems the master queried an unsupported register
			// return 0xff
			return 0xff;
	}
}

void i2cWriteToRegister(uint8_t reg, uint8_t value) {
	switch (reg) {
		case 30:
			// we received a value for the lowByte
			if ( lowByte != value ) {
				// If the value has changed, store this
                lowByte = value;
			}
			// Either way, a new value has been received, so set the PFLB 
			// register
			PFREG0 |= (1 << PFLB);
            //PORTD ^= (1 << I2C_RCVD_LOW);
			break;
		case 31:
			if ( highByte != value ) {
				highByte = value;
			}
			// Either way, a new value has been received, so set the PFHB
			// register
			PFREG0 |= (1 << PFHB);
            //PORTD ^= (1 << I2C_RCVD_HGH);
			break;
        default:
            break;
	}
}

/*
 * Functions we need for PowerFunctions
 */
/*
 * Command Processing
 */
void process_command(uint16_t command) {
    
    start_stop_bit();
    
    for ( uint8_t i = 0; i < 16; i++ ) {
        if ( (0x8000 & (command << i)) != 0 ) {
            send_bit(PAUSE_HIGH);
            //send_string("1");
        } else {
            send_bit(PAUSE_LOW);
            //send_string("0");
        }
    }
    //send_string("\n\r");
    start_stop_bit();
}

void send_bit(uint8_t pause) {
    cycles_count = 0;
    
    // Set PB3 as output, enabling OC1A
    DDRB |= (1 << PB3);
    
    // First send the HIGH MARK
    while ( cycles_count < MARK ) {
        __asm __volatile ("nop");
    }
    
    // Clear PB3 as output, disabling PB3
    DDRB &= ~(1 << PB3);
    
    // Reset the cycles_count & send_command flag
    cycles_count = 0;
    
    // Send nothing, just count the cycles
    while ( cycles_count < pause ) {
        __asm __volatile ("nop");
    }
}

void pause(uint8_t count) {
    uint8_t pause = 0;
    switch ( count ) {
        case 0:
            pause = 4 - channel;
            break;
        case 1:
        case 2:
            pause = 5;
        default:
            pause = 5 + (2 * channel);
            break;
    }
    cycles_count = 0;
    // uint16_t cycles_wait = pause * MAX_MSG_LNGTH;
    // In a lot of other implementations I find references to 77 µs as
    // multiplication factor, which means about 3 cycles (2.9) (!!)
    uint16_t cycles_wait = pause * 3;
    while ( cycles_count < cycles_wait) {
        __asm __volatile ("nop");
    }
    
}

void start_stop_bit(void) {
    send_bit(PAUSE_STARTSTOP);
}

/*
 * Main program loop
 */
int main(void) {
	init_devices();
    
	// Start the needed tasks(s)
    task_set(0);
    task_set(1);

    // Main loop
	while (1) {
		if ( tick_flag) {
			tick_flag = 0;
			task_dispatch();
		}
	}
	return 0;
}

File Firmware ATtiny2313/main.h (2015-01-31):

/*
 * Lego PowerFunctions I2C Slave
 *
 * main.h
 *
 * Author:	Xander Maas, <xander@xjmaas.nl>
 * Created:	17 oct 2014
 *
 * Copyright (c) 2014, Xander Maas
 * Copyright (c) 2010, Russel Bull (Multi-tasking code)
 *
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
 * Warranties:
 *      NONE, USE AT OWN RISK
 *
 * Note(s):
 *      This file is based on code from avrfreaks.net
 *      Thread => [TUT][C]Multi-tasking tutorial part 1
 *      (http://www.avrfreaks.net/forum/tutc-multi-tasking-tutorial-part-1)
 *      The code on which the multi-tasking os based is copyrighted, but free
 *      for any use.
 *
 * Change history:
 *      date        Description
 *      26 Dec 2014 First public release.
 */

/*
 * COMPILE OPTIONS
 */
#ifndef F_CPU
#define F_CPU 8000000UL
#endif

/*
 * Forward function declarations
 */

// Initialization functions
void init_device(void);
void timer0_init(void);
void timer1_init(void);

// Multi-tasking functions
void task_reset(unsigned char task);
void task_set(unsigned char task);
void task_dispatch(void);

// I2C functions
void setupI2C(void);
uint8_t i2cAddress(void);
uint8_t i2cReadFromRegister(uint8_t reg);
void i2cWriteToRegister(uint8_t reg, uint8_t value);

// PowerFunctions functions
void process_command(uint16_t command);
void send_bit(uint8_t pause);
void pause(uint8_t count);
void start_stop_bit(void);

// The tasks we want to perform
void task0(void);
void task1(void);

// Debugging using Serial
void init_serial(void);
void send_string(char *msg);
void converted_byte(char byte1, char byte2);

/*
 * Multi-tasking
 */

// TIMER0 settings/calculations for Multi-tasking
#define T0_PRESCALER    1024
#define T0_F_OUT        100     /* 100 Hz == 10 ms per tick */
#define OCR0A_VALUE     ((((F_CPU / 2) / T0_PRESCALER) / T0_F_OUT) -1)
#define OCR0A_DEBUG     PB2

// Define the number of tasks
#define NUM_TASKS 2

// lsb is high priority task
unsigned char task_bits = 0;

// If non-zero, a tick has elapsed
// Used by TIMER0
volatile char tick_flag = 0;

// Init the timers to 0 on startup
unsigned int task_timers[NUM_TASKS] = {0, 0};

// Value -> bitmask translate table
static const unsigned PROGMEM char bit_mask[] = {1, 2, 4, 16, 32, 64, 128};

/* 
 * Input/Output
 */

#ifdef DEBUG
// DEBUGGING I2C PINS (LED OUTPUTS)
#define I2C_RCVD_LOW	PD0
#define I2C_RCVD_HGH	PD1
#endif

/*
 * I2C
 */

// Version
#define MAJOR_VERSION 	0
#define MINOR_VERSION 	1	
#define REVISION 		1
#define RELEASE 		'R'	//	A == 0x41 == Alpha
							//	B == 0x42 == Bravo
							//	R == 0x52 == Release Candidate
							//	G == 0x47 == Gold Master

// Address pins
#define ADDR_PIN0		PD2
#define ADDR_PIN1		PD3

/*
 * LEGO powerFunctions
 */

// TIMER0 Settings for LEGO Powerfunctions
#define T1_PRESCALER    1
#define T1_F_OUT        38000   /* 38 kHz           */
#define OCR1A_VALUE     ((((F_CPU / 2) / T1_PRESCALER) / T1_F_OUT) -1)

// We count here in half cycles ;)
#define MARK            12      // 6 Cycles
#define PAUSE_STARTSTOP 2 * START_STOP
#define PAUSE_HIGH      2 * HIGH_PAUSE
#define PAUSE_LOW       2 * LOW_PAUSE
#define MAX_MSG_LNGTH   2 * MAX_MESSAGE_LENGTH

// Flags to determine the state of the through I2C received command
volatile uint8_t PFREG0 = 0x00;
#define PFLB			0		// Is set when the low byte has been received
#define PFHB			1		// Is set when the high byte has been received
#define PFCMD0			2		// Is set when a complete command has been
                                // received

volatile uint8_t send_command = 0;
volatile uint16_t cycles_count = 0;

volatile uint8_t calc_pause = 0;

// The place to store our high and low byte(s) of the command
// we want to send to our PF enabled device
volatile uint8_t lowByte;
volatile uint8_t highByte;

// Channel value has already been corrected in the code
// e.g. an address of 0 if channel 1
static volatile uint8_t channel;
volatile uint16_t pfCommand;


// Debugging
char *converted;

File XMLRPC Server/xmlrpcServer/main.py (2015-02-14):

#!/usr/bin/python -u
"""
  LEGO PowerFunctions I2C Server

  File:      main.py
  Author:    Xander Maas  <xander@xjmaas.nl>
  Version:   1.0.2
  Date:      10 oct 2014

  Version history:
     0.1     10 oct 2014 -   Initial version/try
     1.0     31 dec 2014 -   First public release on GitHub
     1.0.1   21 jan 2015 -   Added an additional test for the checksum nibble of
                             command. Also added a test to check if the command is
                             being sent to the correct channel
     1.0.2   01 feb 2015 -   Added a check for installed boards
     1.1.0   12 feb 2015 -   Added support for B+/A+/Compute Module and RPi2B

  LICENSE INFO:
    AS FOR NOW THIS SOFTWARE IS NOT TO BE PUBLISHED WITHOUT MY EXPLICIT
    WRITTEN PERMISSION ONLY.

    Copyright (c) Xander Maas, 2014-2015

  This programm will create a tcp based server, which translates the
  commands sent from (another) device over TCP/IP to the I2C command(s)
  which will be sent over the I2C bus of the RPi
"""

# Our import(s)
#from tcpServer import *
from i2c import *
from i2cBoard import *
from xmlServer import *
import logging
import smbus
import sys

i2cBoards = []
i2cBus = i2c().bus

if __name__ == '__main__':
	print 'Running'
	print 'Identifying/detecting boards'
	addressRange = range(0x40, 0x43)
	for i in addressRange:
		board = i2cBoard(i, i2cBus)
		if board.installed == True:
			i2cBoards.append(board)

	if (len(i2cBoards) < 1):
		print ''
		print 'ERROR: No boards detected, make sure at least one board has been installed'
		print ''
		sys.exit(2)

	for board in i2cBoards:
		if board.identified == True:
			print 'Seems we have a legit board at the address ' + hex(board.address)
			print 'Board version: ' + board.version

	# Set up our logging
	logging.basicConfig(level=logging.DEBUG)

	# Next we initialize our XMLRPC Server
	server = xmlServer('0.0.0.0', 9000)
	logging.debug('Just asked the server to start')

	# Define our function(s)
	def installedBoards():
		logging.debug('==== main.installedBoards() ====')
		return boardsDict()

	def returnVersion():
		logging.debug('==== main.returnVersion() ====')
		return '1.0.2'

	def pfCommand(command, channel = 1):
		logging.debug('==== main.pfCommand() ====')
		logging.debug('Received a PowerFunctions Command => %s', str(hex(command)))
		logging.debug('for channel => %d', channel)
		
		# Test if the channel within bounds (1 ... 4)
		if (channel < 0 or channel > 4):
			logging.debug('Seems the requested channel is out of bounds')
			return dict(status = False, description = 'Channel out of bounds')

		# Check if the checksum is correct for this command
		# Low Nibble High Byte
		nib1 = command >> 12 & 0xf
		# High Nibble High Byte
		nib2 = command >> 8 & 0xf
		# High Nibble Low Byte
		nib3 = command >> 4 & 0xf
		# Checksum = Low Nibble Low Byte
		chksum = command & 0xf
		logging.debug(' Our nibbles: 1 = %s, 2 = %s, 3 = %s, chk = %s', str(hex(nib1)), str(hex(nib2)), str(hex(nib3)), str(hex(chksum)))
		calculatedChksum = 0xf ^ nib1 ^ nib2 ^ nib3
		if (chksum != calculatedChksum):
			desc = "Checksum for the command isn't correct. Expected " + str(hex(calculatedChksum)) + ", got " + str(hex(chksum))
			return dict(status = False, description = desc)
		# Test if the requested channel is available (board installed/connected)
		boardAvailable = channelAvailable(channel)
		address = boardAvailable['address']
		if boardAvailable['status'] == False:
			logging.debug('Seems the requested channel is unavailable (board %s not installed)', str(hex(address)))
			return dict(status = False, description = 'Channel (board ' + str(hex(address)) + ') not installed')

		# As we already have the nibble with the channel information, test if the 
		# board will be addressed
		_channel = (nib1 & 0x3) + 1
		if (_channel != channel):
			descr = "You cannot send this command to channel " + str(channel) + " as the command is created for channel " + str(_channel)
			logging.debug('Wrong channel is chosen. Command is for channel %d, but channel %d is requested', _channel, channel)
			return dict(status = False, description = descr)

		# Seems we got an available channel/board, next we have to send the
		# command to the board
		logging.debug('Going to send the command %s to the requested board %s', str(hex(command)), str(hex(address)))
		logging.debug('We got %d boards', len(i2cBoards))
		sendCommand(command, boardAvailable['board'])

		# Give our client a status to act on
		return dict(status = True, description = 'Success')

	# Register the functions
	server.server.register_function(installedBoards)
	server.server.register_function(returnVersion)
	server.server.register_function(pfCommand)

	# Send the command to the board
	def sendCommand(command, board):
		logging.debug('==== main.sendCommand() ====')
		# First we have to break up our command into two (2) bytes
		lowByte = command & 0xff # should give 0x17
		highByte = command >> 8 # should give 0x81
		logging.debug('Sending command to board => %s', str(hex(board.address)))
		logging.debug('Command => %s %s',  str(hex(highByte)), str(hex(lowByte)))

		# Now we've got our seperated bytes, we can send them.
		# lowByte goes into register 0x30
		# highByte goes into register 0x31
		board.sendPowerFunctionCommand(30, lowByte)
		board.sendPowerFunctionCommand(31, highByte)

	# Test if the channel is available
	def channelAvailable(channel = 1):
		logging.debug('==== main.channelAvailable() ====')
		i2cAddress = 0x40 + (channel - 1)
		logging.debug('We want to send a command to I2C device at address %s', str(hex(i2cAddress)))
		for board in i2cBoards:
			if board.address == i2cAddress:
				logging.debug('We found the requested board')
				return dict(status = True, board = board, address =  i2cAddress)
				break
		return dict(status = False, board = board, address = i2cAddress)

	# We have to convert our i2cBoards array to something we can return
	def boardsDict():
		logging.debug('==== main.boardsDict() ====')
		boards = []
		for board in i2cBoards:
			if board.installed == True:
				boards.append(dict(address = hex(board.address), version = board.version))
		return boards

	try:
		print 'Use Control-C to exit)'
		server.server.serve_forever()
	except KeyboardInterrupt:
		print 'Exiting'

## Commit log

2014-12-26 Eagle file(s) added
    These are the Eagle files for the project. The files are made with
    version 7.2.0 and contain at the moment just the schematics.
    I still have to create the PCB layout(s)
    [Converter Board.sch, RPi Lego Server Daughter Board v1.sch, RPi Lego Server Prototype Setup.sch]
2014-12-29 Uploaded new schematics, both interconnect board and IR board. USB connector (for power) has been moved to interconnect board. Also added routed PCB designs
    [Converter Board.sch, RPi Lego Server Daughter Board v1_0A.brd, RPi Lego Server Daughter Board v1_0A.sch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]
2015-01-15 Some minor corrections in PCB/schematic design
    Corrected JP2 (I2C) Address headers, so they are oriented correctly
    Also renamed the PowerFunctions board to reflect it's actual function:
    I2C Lego PowerFunctions Board
    [I2C Lego PowerFunctions Board v1_0B.brd, I2C Lego PowerFunctions Board v1_0B.sch]
2015-01-15 Added a .gitignore
    [RPi Lego Server Daughter Board v1_0A.brd, RPi Lego Server Daughter Board v1_0A.sch]
2015-01-21 Updated xmlrpcServer and xmlrpc_debug
    xmlrpcServer (v1.0.1):
    Added an additional test for the checksum nibble of command. Also added
    a test to check if the command is being sent to the correct channel
    xmlrpc_debug (v1.0.1):
    Recreated version, with commandline options. Also cleaned (some) code.
    Seems a good debug/test util to me ;)
    [main.py]
2015-01-31 Scratch interface added, firmware updates
    - Added a Scratch (1.4) interface/python script, so we can control
    Lego Powerfunctions from within Scratch (documentation not done yet,
    read source ;))
    - Added a new firmware which *should* support Combo PWM mode. (Still
    some issues with channel 2+)
    [main.c, main.h, main.py]
2015-02-05 Added Scratch 1.4 test files
    - Start the xmlrpcServer on your Raspberry Pi (e.g. ./main.py)
    - Start the ScratchClient on your client or Raspberry Pi
    ./main -s 192.168.32.11 -x http://127.0.0.1:9000
    -s is the IP address of the computer running Scratch
    -x is the URL for the xmlrpcServer e.g. http://127.0.0.1:9000 if you
    are
    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
2015-02-05 Added a new version of the board
    Added a new board version, this one should fit a Raspberry PI A or B
    model.
    Also added impressions of the boards, rendered in SketchUp
    [Lego PowerFunctions I2C Board.brd, Lego PowerFunctions I2C Board.sch, Lego PowerFunctions I2C RPi Connect.brd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]
2015-02-14 Raspberry Pi board detection code updated
    Added a quick (and dirty) hack to identify the A+, B+, Compute Module
    and Raspberry Pi 2 B models.

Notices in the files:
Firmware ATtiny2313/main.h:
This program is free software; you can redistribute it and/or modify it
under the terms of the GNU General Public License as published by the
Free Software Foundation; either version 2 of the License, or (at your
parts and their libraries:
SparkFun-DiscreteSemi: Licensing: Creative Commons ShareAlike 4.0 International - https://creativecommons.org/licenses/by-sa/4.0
